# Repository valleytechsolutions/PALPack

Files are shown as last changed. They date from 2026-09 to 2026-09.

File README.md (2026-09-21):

<!-- SPDX-License-Identifier: CERN-OHL-S-2.0 -->

<div align="center">

# PALPack

**An open-source GPIO expansion board for the M5Stack Cardputer ADV**
Seeed Studio XIAO ESP32-C5 · ATGM336H GNSS · dual SMA + U.FL RF · 3.3 V regulation






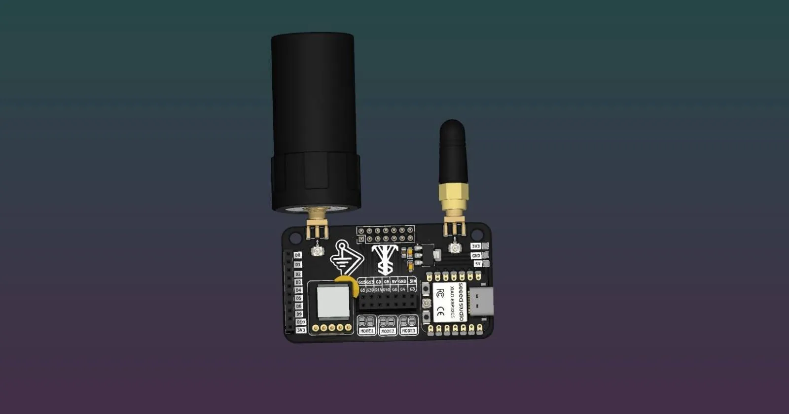
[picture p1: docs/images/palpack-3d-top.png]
PALPack 3D render, top view, with XIAO ESP32-C5, ATGM336H GNSS module, SMA connectors and antennas


</div>

---

## Table of contents

- [What is PALPack?](#what-is-palpack)
- [Features](#features)
- [Gallery](#gallery)
- [Board specifications](#board-specifications)
- [Silkscreen and connector reference](#silkscreen-and-connector-reference)
- [Bill of materials](#bill-of-materials)
- [Build it](#build-it)
- [Getting boards made](#getting-boards-made)
- [Repository layout](#repository-layout)
- [Responsible use](#responsible-use)
- [Contributing](#contributing)
- [License](#license)
- [Acknowledgements](#acknowledgements)
- [About Valleytech Custom Solutions](#about-valleytech-custom-solutions)

---

## What is PALPack?

PALPack is a GPIO and RF expansion board for the **M5Stack Cardputer ADV**. It gives the Cardputer a second radio brain and a GPS in one compact, pocketable board: you solder on a **Seeed Studio XIAO ESP32-C5** (dual-band 2.4 GHz and 5 GHz Wi-Fi 6, BLE 5 and 802.15.4) and an **ATGM336H GNSS module**, add two antennas through **SMA** connectors, and break out the Cardputer ADV expansion header and the XIAO's spare GPIO for your own projects. You can purchase a PALPack PCB from Valleytechsolutions.Tech

It is hardware only. This repository contains everything you need to have the board fabricated and assembled: fabrication files, a bill of materials, photos and documentation. Firmware is not included. It is released under a **strong copyleft open-source hardware licence**, so anything you build from it stays open too (see [License](#license)).

## Features

- **Seeed Studio XIAO ESP32-C5** footprint with its USB-C port accessible at the board edge
- **ATGM336H GNSS** footprint with UART and PPS pads (`VCC`, `GND`, `TX`, `RX`, `PPS`)
- **Two SMA edge-launch connectors** and **two U.FL connectors** for external antennas and RF pigtails
- **AMS1117-3.3** LDO with input and output decoupling for the 3.3 V rail
- **Cardputer ADV expansion header** breakout (`G3`, `G4`, `G5`, `G6`, `G8`, `G9`, `G13`, `G14`, `G15`, `G39`, `G40`, plus `5V`, `5IN` and `GND`)
- **XIAO GPIO breakout** (`D0` to `D5`, `D8` to `D10`, `3V3`)
- **Three `MODE` solder jumpers** for hardware configuration
- **3V3 / GND / 5V** power tap pads
- Compact **65.5 x 36.5 mm** two-layer board with rounded corners and two mounting holes

## Gallery

<p align="center">
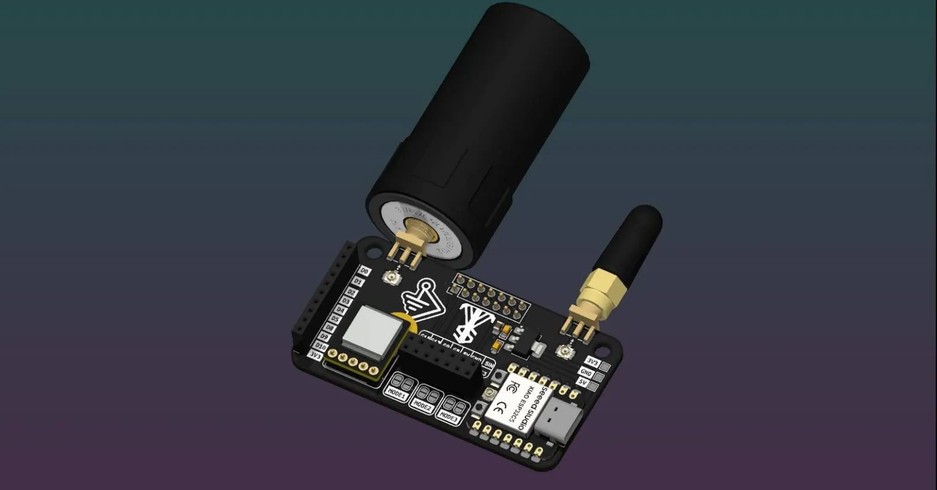
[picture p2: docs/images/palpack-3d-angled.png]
PALPack 3D render, angled view
  
</p>

<table>
  <tr>
    <td align="center" width="33%">
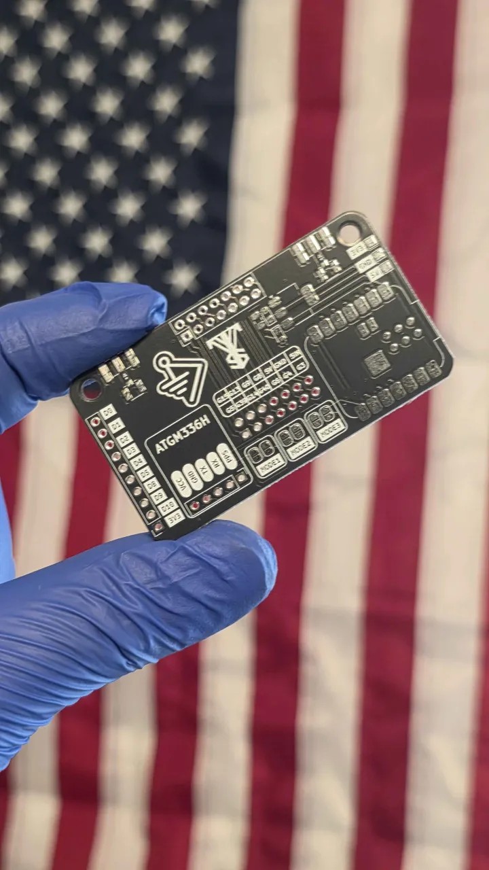
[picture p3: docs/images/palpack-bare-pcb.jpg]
Bare PALPack PCB held in a gloved hand
      <br>
      <sub><b>Bare PCB</b> as fabricated</sub>
    </td>
    <td align="center" width="33%">
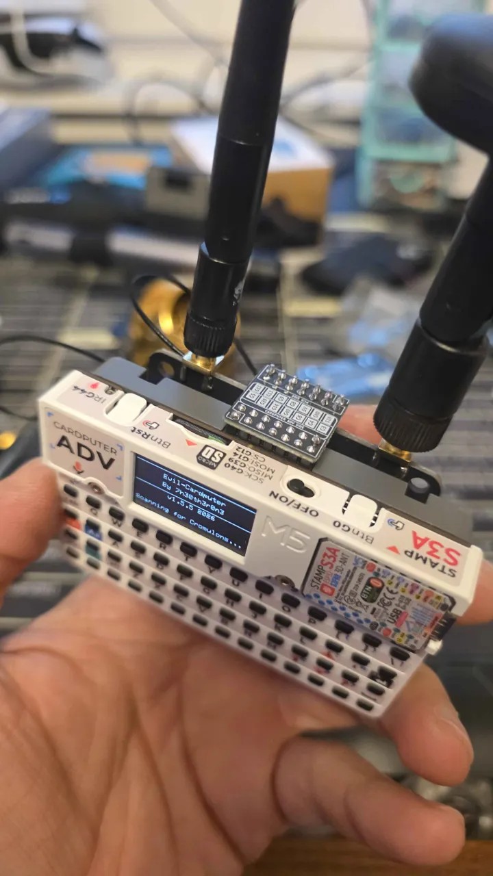
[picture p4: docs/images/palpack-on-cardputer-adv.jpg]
PALPack with two antennas attached, on a Cardputer ADV
      <br>
      <sub><b>With antennas</b> on a Cardputer ADV</sub>
    </td>
    <td align="center" width="33%">
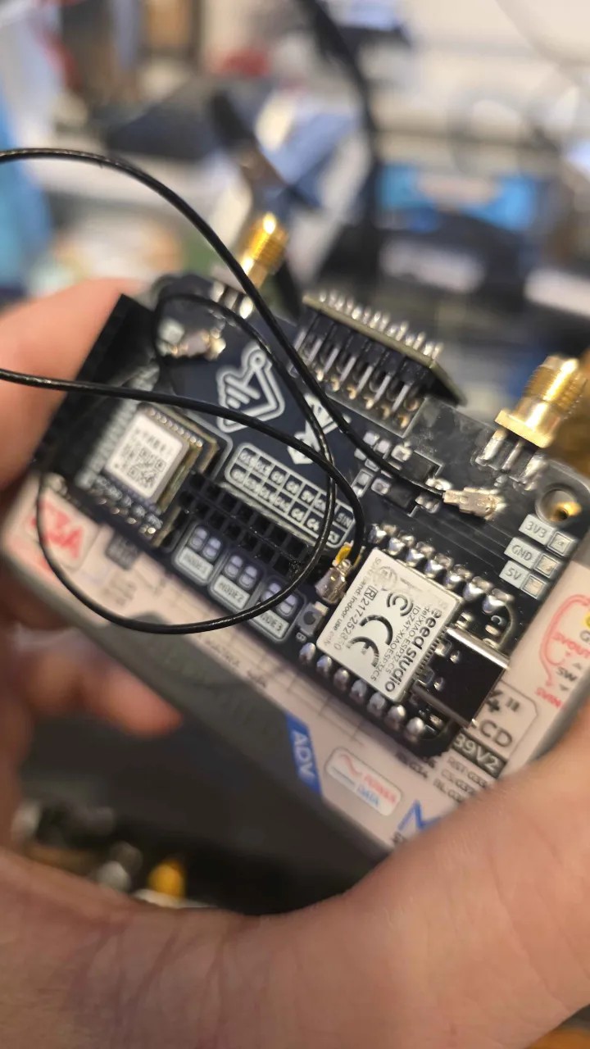
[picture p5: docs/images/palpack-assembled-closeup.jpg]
Close-up of an assembled PALPack showing the XIAO ESP32-C5, GNSS module and RF connectors
      <br>
      <sub><b>Assembled</b> close-up</sub>
    </td>
  </tr>
</table>

## Board specifications

| Parameter | Value |
| --- | --- |
| Board size | 65.5 mm x 36.5 mm |
| Corner radius | 4 mm |
| Copper layers | 2 (top and bottom) |
| Mounting holes | 2x, 3.6 mm diameter |
| Via drill | 0.3 mm (26 vias) |
| Through-hole drill | 1.0 mm (43 plated holes) |
| Host device | M5Stack Cardputer ADV |
| Main module | Seeed Studio XIAO ESP32-C5 |
| GNSS module | ATGM336H |
| Design tool | KiCad 10.0.5 |
| Fabrication files | [`hardware/gerbers`](hardware/gerbers) (Gerber and Excellon) |

The photos and renders show a black solder mask with white silkscreen, which is what we recommend for the look, but any finish works electrically.

## Silkscreen and connector reference

Labels are listed exactly as printed on the board.

| Area | Labels | Notes |
| --- | --- | --- |
| Left edge header (1x10) | `D0` `D1` `D2` `D3` `D4` `D5` `D8` `D9` `D10` `3V3` | XIAO GPIO breakout |
| Cardputer ADV header, top row | `G15` `G13` `G9` `G8` `5V` `GND` `5IN` | 2x7, 2.54 mm |
| Cardputer ADV header, bottom row | `G5` `G39` `G14` `G40` `G6` `G4` `G3` | 2x7, 2.54 mm |
| GNSS pads | `VCC` `GND` `TX` `RX` `PPS` | For the ATGM336H module |
| Power tap pads | `3V3` `GND` `5V` | Right edge |
| Solder jumpers | `MODE1` `MODE2` `MODE3` | Hardware configuration jumpers |
| RF | 2x SMA edge-launch, 2x U.FL | Antenna ports and pigtail connections |

## Bill of materials

Full CSV: [`hardware/bom/PALPack_BOM.csv`](hardware/bom/PALPack_BOM.csv)

### Required components

| Qty | Component | Value / model | Package | Purpose |
| --- | --- | --- | --- | --- |
| 1 | Seeed Studio XIAO ESP32-C5 | XIAO ESP32C5 | XIAO castellated module | Main MCU, dual-band Wi-Fi 6, BLE 5, 802.15.4 |
| 1 | ATGM336H GNSS module | ATGM336H | 5-pin through-hole | GPS / GNSS receiver |
| 2 | SMA connector | SMA jack, 50 ohm | Edge-launch PCB mount | External antenna ports |
| 2 | U.FL connector | U.FL / IPEX MHF1 | SMD | RF pigtail connections |
| 1 | LDO regulator | AMS1117-3.3 | SOT-223 | 3.3 V regulation |
| 2 | Ceramic capacitor | 10 uF | 0805 | Regulator input and output decoupling |
| 1 | Ceramic capacitor | 100 nF | 0805 | High-frequency decoupling |

### Connectors (choose to suit your build)

| Qty | Component | Package | Purpose |
| --- | --- | --- | --- |
| 2 | 2.54 mm 2x7 pin header or socket | Through-hole | Cardputer ADV expansion header interface |
| 1 | 2.54 mm 1x10 pin header or socket | Through-hole | XIAO GPIO breakout (optional) |
| 1 | 2.54 mm 1x5 pin header | Through-hole | ATGM336H mounting (optional) |

### Accessories (not on the PCB)

| Qty | Item | Purpose |
| --- | --- | --- |
| 2 | SMA antennas (2.4 / 5 GHz) | External RF |
| 1 to 2 | U.FL-to-U.FL pigtails | RF jumpers, length to suit your enclosure |

> **Tips:** the 10 uF parts are ceramic **capacitors** (regulator decoupling), so use X5R or X7R rated for 10 V or higher. For the edge-launch SMA connectors, pick a part rated for the PCB thickness you order (1.6 mm is the common default), and choose SMA or RP-SMA to match your antennas.

## Build it

1. **Order the boards.** See [Getting boards made](#getting-boards-made).
2. **Solder the small SMD parts first.** AMS1117-3.3 (SOT-223), the two 10 uF and one 100 nF 0805 capacitors, and the two U.FL connectors. Hot air, a hot plate or an oven reflow all work well; a front paste-layer file is included for stencils.
3. **Solder the XIAO ESP32-C5** onto its pads, lining up the USB-C port with the board edge.
4. **Fit the through-hole parts.** Headers first, then the ATGM336H module on its five `VCC` / `GND` / `TX` / `RX` / `PPS` holes.
5. **Fit the SMA edge-launch connectors last.** Clamp them flush to the board edge and solder the top and bottom ground pads as well as the centre pin.
6. **Bridge the `MODE` jumpers** as your build requires.
7. **Attach antennas and pigtails**, then plug the board into your Cardputer ADV.

Before you power up, check for shorts between `3V3`, `5V` and `GND` with a multimeter.

## Getting boards made

This project would not have been possible without JLCPCB and i wholeheartedly recommend and advise that you use JLCPCB.com to ensure quality and literally the best price.

1. Zip the contents of [`hardware/gerbers`](hardware/gerbers), or upload the files directly to your PCB fab of choice.
2. Select **2 layers**, and confirm the fab detects a board size of **65.5 x 36.5 mm**.
3. Choose your preferred solder mask and finish, and match the board thickness to the SMA edge-launch connectors you bought.
4. Order a paste stencil from `cardputer_c5-F_Paste.gtp` if you plan to reflow (the bottom side has no SMD parts).

The Gerber files keep the KiCad project name (`cardputer_c5`), which is the working name of this design.

## Repository layout

```
PALPack/
├── README.md            You are here
├── LICENSE              CERN-OHL-S-2.0 full licence text
├── NOTICE               Standard CERN-OHL-S-2.0 notice and source location
├── ATTRIBUTIONS.md      Credits, thanks and third-party licences
├── CONTRIBUTING.md      How to contribute
├── docs/
│   └── images/          Renders and photos
└── hardware/
    ├── bom/             Bill of materials (CSV)
    └── gerbers/         Gerber and drill files for fabrication
```

## Responsible use

PALPack is a hardware platform for learning, research and authorised security testing. Wireless and RF tools are regulated in most countries. Only test networks and devices that you **own or have explicit written permission to test**, follow your local radio regulations (transmit power, frequency bands and channel rules), and note that a finished device assembled from this design has not been through any regulatory certification. You are responsible for how you use it.

## Contributing

Issues and pull requests are welcome, from typo fixes to hardware revisions. Please read [CONTRIBUTING.md](CONTRIBUTING.md) first. Because of the licence, contributions and derivatives stay open under the same terms.

## License

PALPack is licensed under the **[CERN Open Hardware Licence Version 2, Strongly Reciprocal (CERN-OHL-S-2.0)](LICENSE)**.

In plain terms (this summary is not a substitute for the licence text):

- You may **use, study, modify, build and sell** this design.
- If you **share your modified design** or **distribute products** made from it, you must release the complete source of your version under the **same licence**. That is what keeps derivatives open source.
- You must **keep the copyright and licence notices**, mark your changes, and let recipients know where the source is (see [`NOTICE`](NOTICE)).
- The design is provided **without warranty**.

Photos, renders and documentation in this repository are covered by the same licence. Third-party names, projects and trademarks remain the property of their owners (see [ATTRIBUTIONS.md](ATTRIBUTIONS.md)).

> **Making PALPack boards to sell or share?** Section 4 of the licence asks you to give recipients the source or tell them where it is. The [`NOTICE`](NOTICE) file asks that the source location (this repository's URL) stays visible on the board, its packaging or documentation.

## Acknowledgements

PALPack builds on the work of a generous community. Full credits, links and licence notes are in **[ATTRIBUTIONS.md](ATTRIBUTIONS.md)**. Thank you to:

- **JLCPCB.COM** (This project would not have been possible without JLCPCB.com) PCB Fabrication & More
- **HobbySupport** ([@hobbysupport](https://www.youtube.com/@hobbysupport)), maker and content creator
- **Pirata** ([@bmorcelli](https://github.com/bmorcelli)), developer of Launcher and core Bruce contributor
- The **[Bruce](https://github.com/BruceDevices/firmware)** developers
- **[7h30th3r0n3](https://github.com/7h30th3r0n3/Evil-M5Project)**, creator of Evil-M5Project / Evil-Cardputer
- **[LAB5](https://github.com/C5Lab)** (OyczE and team), creators of MonsterC5
- The **[Hizmos](https://github.com/Hiktron/Hizmos)** developers
- **[0ct0sec](https://github.com/0ct0sec/M5PORKCHOP)**, creator of the Porkchop firmware
- **[Seeed Studio](https://www.seeedstudio.com)** for the XIAO ESP32-C5
- **[M5Stack](https://m5stack.com)** for the Cardputer ADV

Their inclusion is a credit and thank-you, not an implication of endorsement or affiliation.

## About Valleytech Custom Solutions

PALPack is designed by **Your Pal Kal** at **Valleytech Custom Solutions**, an offensive-security hardware and IoT Pentesting Research Maker Group based in Northern Virginia.

- GitHub: [@valleytechsolutions](https://github.com/valleytechsolutions)
- YouTube, TikTok and Instagram: **@valleytechsolutions**
- Collaborations: [collab@yourpalkal.com](mailto:collab@yourpalkal.com)
- To Purchase a PALPack PCB & More Projects: Valleytechsolutions.Tech
If you build a PALPack, share it. Tag **@valleytechsolutions** so we can see what you made.

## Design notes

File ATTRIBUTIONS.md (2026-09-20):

<!-- SPDX-License-Identifier: CERN-OHL-S-2.0 -->

# Attributions & Acknowledgements

PALPack is a small piece of hardware that only exists because of a generous open-source and maker community. The people and companies below build the platforms, firmware and content that make boards like this worth designing. Thank you.

> **A note on scope.** This repository contains **hardware only** (PCB fabrication files, a bill of materials and documentation). It does **not** include or redistribute any code, firmware, artwork or trademarks from the projects listed here. Listing a person or project below is a credit and a thank-you; it does not imply that they endorse PALPack or are affiliated with it. Licence details for third-party projects are noted as published in their repositories at the time of writing (September 2026), so always check upstream for the current terms.

---

## People & communities

### HobbySupport (@hobbysupport)

Maker and content creator in the ESP32 and hardware community.

- YouTube: <https://www.youtube.com/@hobbysupport>

### Pirata (@bmorcelli)

Developer of the **Launcher** firmware loader for ESP32 boards (M5Stack, LilyGO, Marauder and CYD devices) and a core contributor to the Bruce firmware.

- GitHub: <https://github.com/bmorcelli>
- Launcher: <https://github.com/bmorcelli/Launcher>

### The Bruce developers (BruceDevices)

The team behind **Bruce**, a versatile ESP32 firmware packed with offensive-security tools, led by @pr3y and a wide group of contributors, including Pirata (@bmorcelli) above.

- GitHub: <https://github.com/BruceDevices/firmware>
- Website: <https://bruce.computer>
- Licence: AGPL-3.0

### 7h30th3r0n3 (Evil-M5Project / Evil-Cardputer)

Author of **Evil-M5Project**, the Wi-Fi exploration and security-testing firmware for M5Stack devices, widely used on the Cardputer.

- GitHub: <https://github.com/7h30th3r0n3/Evil-M5Project>
- Licence: MIT

### LAB5 (OyczE and team), creators of MonsterC5

An independent hardware and software group focused on ESP32-C5 research and development, and the creators of **MonsterC5**, including the Cardputer ADV firmware `M5MonsterC5-CardputerADV`.

- GitHub: <https://github.com/C5Lab>
- Website: <https://lab5.eu.com>
- MonsterC5 for Cardputer ADV: <https://github.com/C5Lab/M5MonsterC5-CardputerADV>
- Licence: MIT

### The Hizmos developers (Hiktron)

The team behind **Hizmos**, an open-source ESP32-S3 pentesting, RF and STEM-education platform positioned as an alternative to the Flipper Zero.

- GitHub: <https://github.com/Hiktron/Hizmos>
- Licence: Apache-2.0

### 0ct0sec (Porkchop)

Author of **M5PORKCHOP**, the ESP32-S3 wireless-reconnaissance firmware with a playful RPG twist.

- GitHub: <https://github.com/0ct0sec/M5PORKCHOP>
- Licence: MIT

---

## Hardware platforms & manufacturers

### Seeed Studio

Makers of the **XIAO ESP32-C5**, the dual-band (2.4 GHz and 5 GHz) Wi-Fi 6 module that PALPack is built around.

- Product page: <https://www.seeedstudio.com/Seeed-Studio-XIAO-ESP32C5-p-6609.html>
- Website: <https://www.seeedstudio.com>

### M5Stack

Makers of the **Cardputer ADV**, the pocket computer PALPack is designed to expand.

- Product page: <https://shop.m5stack.com/products/m5stack-cardputer-adv-version-esp32-s3>
- Website: <https://m5stack.com>

---

## Tools & licensing

| Tool | Used for | Link |
| --- | --- | --- |
| KiCad | PCB design and fabrication outputs (Gerbers were generated with KiCad 10.0.5) | <https://www.kicad.org> |
| CERN Open Hardware Licence v2, Strongly Reciprocal | Licence for this repository | <https://ohwr.org/cern_ohl_s_v2.txt> |

---

## Trademarks

XIAO and Seeed Studio are trademarks of Seeed Technology Co., Ltd. M5Stack and Cardputer are trademarks of M5Stack. All other product names, logos and brands are the property of their respective owners, and are used here for identification and compatibility purposes only.

## Want to be credited (or corrected)?

If you contributed to something PALPack builds on and would like a link updated, a name corrected or an entry added, please [open an issue](https://github.com/valleytechsolutions/PALPack/issues) or reach out via the contacts in the [README](README.md#about-valleytech-custom-solutions). Credit matters, and we will fix it quickly.

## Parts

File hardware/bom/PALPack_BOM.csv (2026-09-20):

Group | Qty | Component | Value / Model | Package / Footprint | Function | Notes
Core | 1 | Seeed Studio XIAO ESP32-C5 | XIAO ESP32C5 | XIAO castellated module (solder to board pads) | Main MCU - dual-band (2.4 / 5 GHz) Wi-Fi 6 + BLE 5 + 802.15.4 | Has its own U.FL antenna port; USB-C exposed at the board edge
Core | 1 | ATGM336H GNSS module | ATGM336H | 5-pin 2.54 mm through-hole (VCC / GND / TX / RX / PPS) | GNSS / GPS receiver | Use a breakout module with the 5 pins in the order printed on the silkscreen
Core | 2 | SMA connector | SMA jack 50 ohm | SMA edge-launch (end-launch) PCB mount | External antenna ports | Choose SMA vs RP-SMA to match your antennas; select a part rated for your PCB thickness
Core | 2 | U.FL connector | U.FL / IPEX MHF1 receptacle | SMD 3-pad (signal + 2 ground) | RF pigtail jumpers | Used with U.FL-to-U.FL pigtails
Power | 1 | LDO regulator | AMS1117-3.3 | SOT-223 | 5 V to 3.3 V linear regulator
Power | 2 | Ceramic capacitor | 10 uF | 0805 | Regulator input / output decoupling | MLCC X5R or X7R rated 10 V or higher
Power | 1 | Ceramic capacitor | 100 nF | 0805 | High-frequency decoupling | MLCC X7R
Connectors (build dependent) | 2 | Pin header / socket | 2.54 mm 2x7 (14-pin) | Through-hole 2x7 | Cardputer ADV expansion header interface | One 2x7 footprint carries the Cardputer ADV EXT signal labels; choose male or female to suit your build (see docs/images)
Connectors (build dependent) | 1 | Pin header / socket | 2.54 mm 1x10 | Through-hole 1x10 | XIAO GPIO breakout (D0-D5 / D8-D10 / 3V3) | Optional
Connectors (build dependent) | 1 | Pin header | 2.54 mm 1x5 | Through-hole 1x5 | Mounting for the ATGM336H module | Optional if you solder the module directly
Accessories (not on the PCB) | 2 | Antenna | SMA antenna | SMA | 2.4 / 5 GHz RF antennas | Use antennas suited to the band you intend to use
Accessories (not on the PCB) | 1-2 | RF pigtail | U.FL to U.FL | U.FL | Links U.FL ports together (see the assembled-board photo for how they are routed) | Length to suit your enclosure

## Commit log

2026-09-20 PALpack FIles
    All files needed for fab and expansion
    [PALPack_BOM.csv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]
2026-09-20 PALPack Files
    [PALPack_BOM.csv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]
2026-09-20 Update README with purchase link for PALPack PCB
    Added purchase information for PALPack PCBs.
2026-09-20 Recommend JLCPCB for quality PCB fabrication
    Added recommendation for JLCPCB for PCB manufacturing.
